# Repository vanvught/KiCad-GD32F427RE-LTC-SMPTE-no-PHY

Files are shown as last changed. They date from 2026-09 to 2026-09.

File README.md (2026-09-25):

# KiCad GD32F427RE LTC-SMPTE no PHY

Firmware [https://github.com/vanvught/GD32F427RE-LTC-SMPTE](https://github.com/vanvught/GD32F427RE-LTC-SMPTE)

More information [https://www.gd32-dmx.org](https://www.gd32-dmx.org)

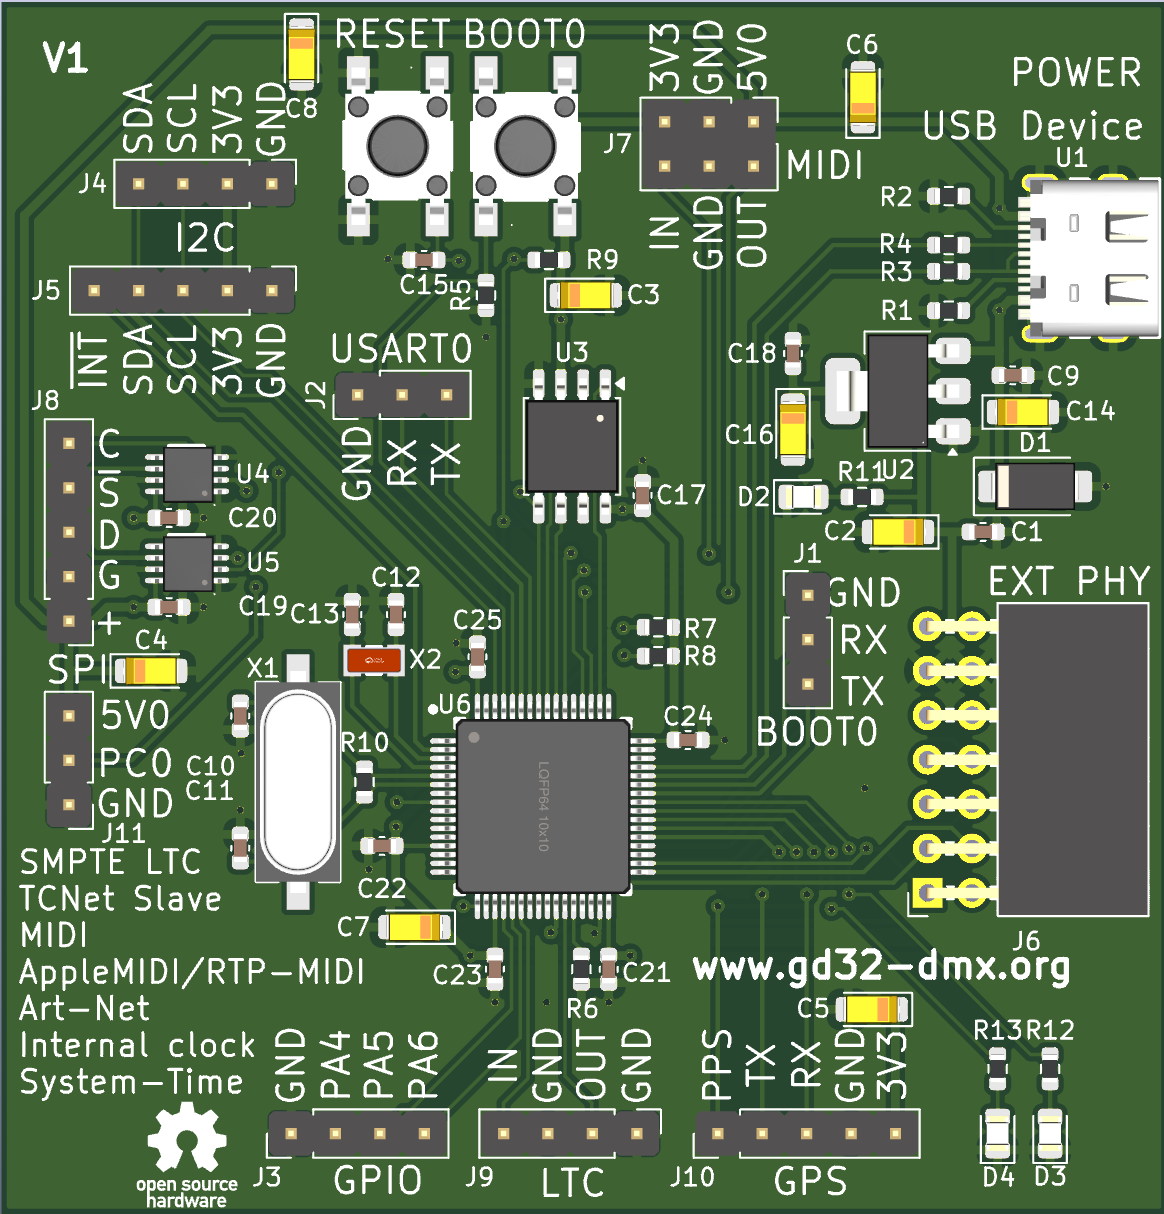
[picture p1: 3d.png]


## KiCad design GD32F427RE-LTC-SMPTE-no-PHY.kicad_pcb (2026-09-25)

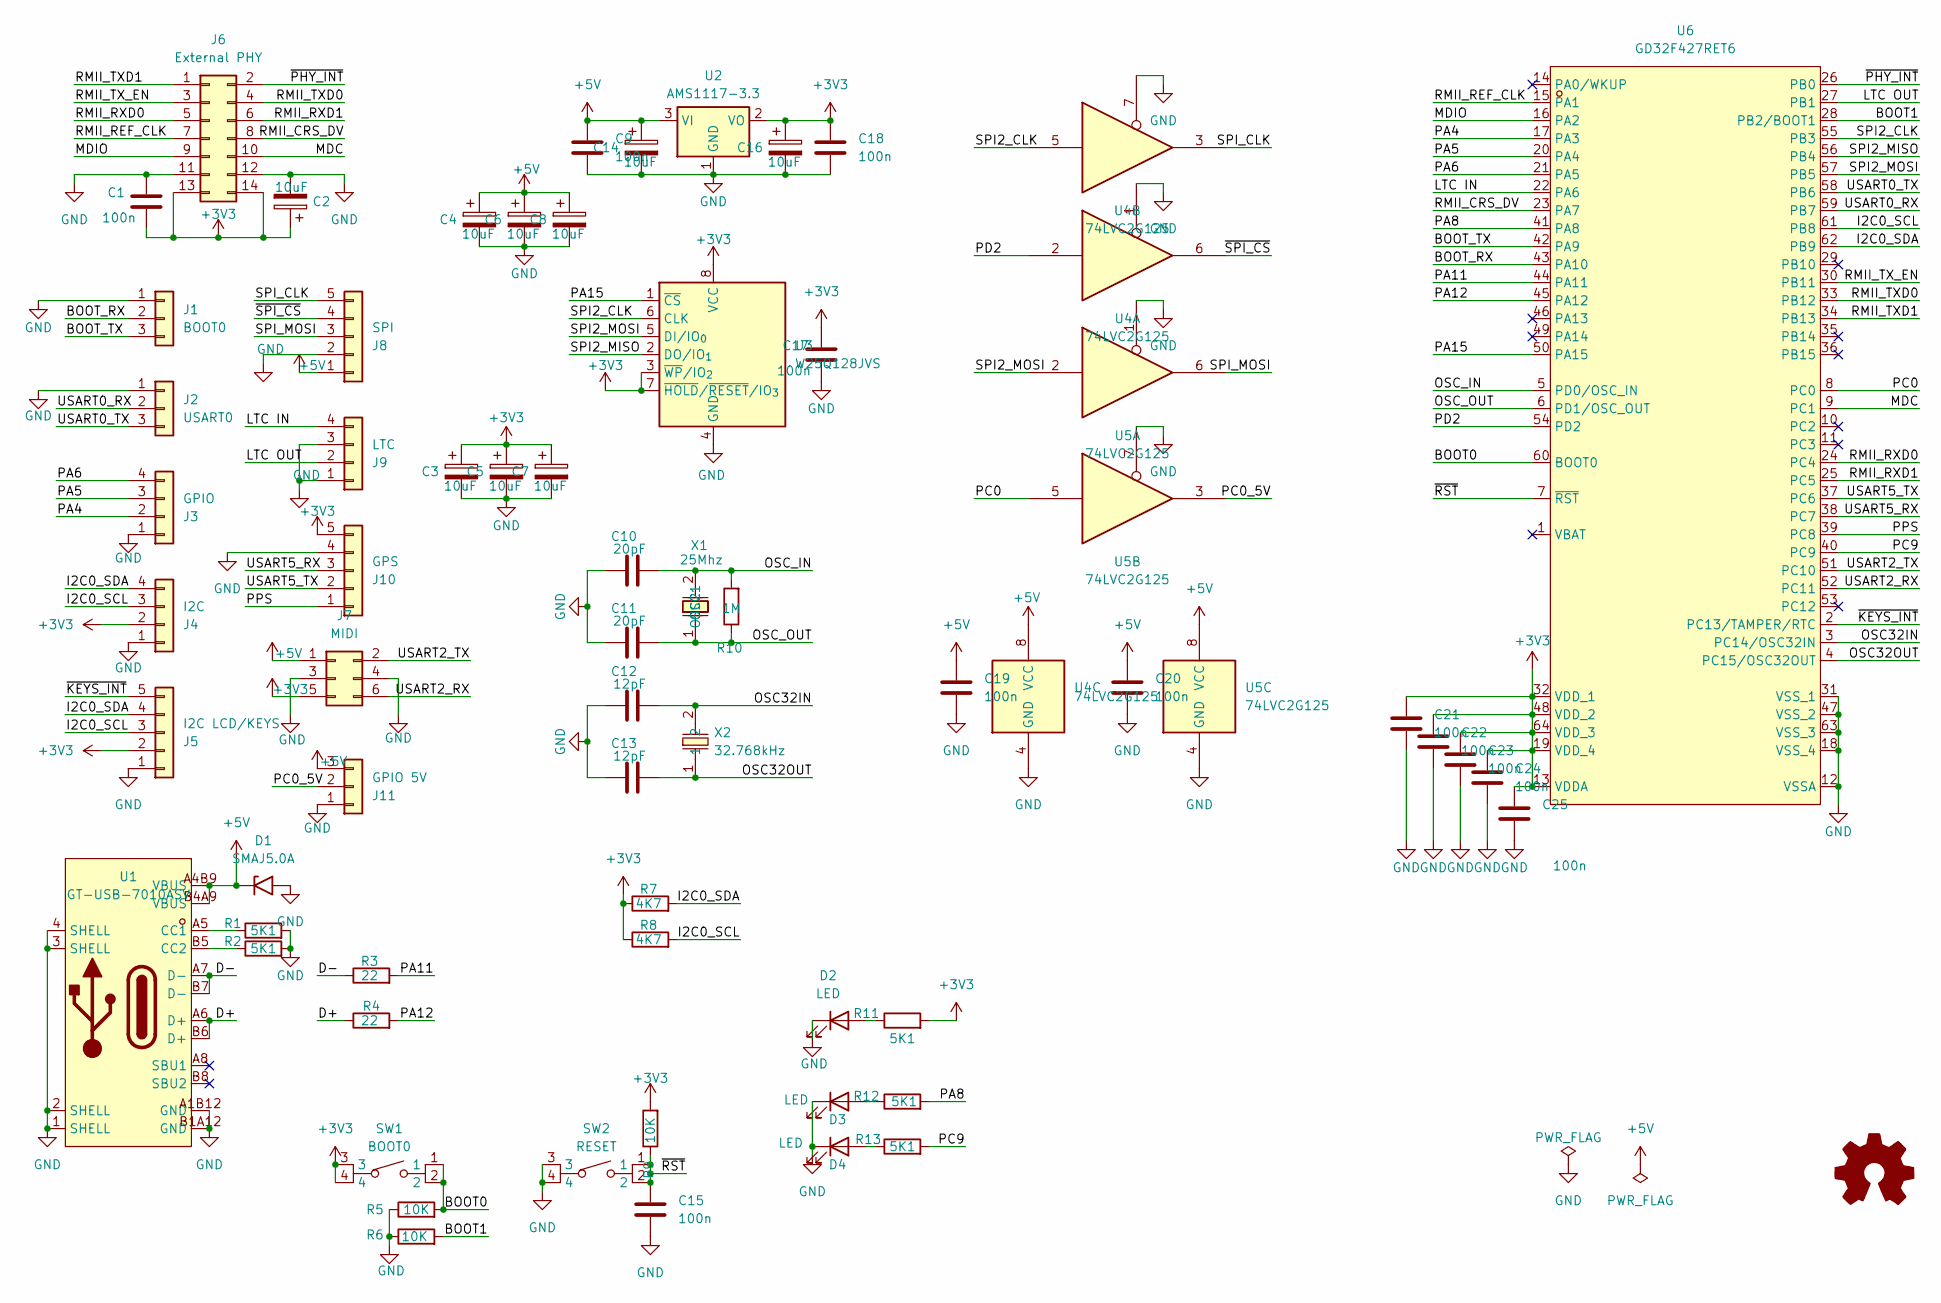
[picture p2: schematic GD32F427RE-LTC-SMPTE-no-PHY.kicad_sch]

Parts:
C1, C9, C15, C17, C18, C19, C20, C21, C22, C23, C24, C25: 100n; C_0603_1608Metric; LCSC Part C14663
C2, C3, C4, C5, C6, C7, C8, C14, C16: 10uF; CP_EIA-3216-18_Kemet-A; LCSC Part C7171
C10, C11: 20pF; C_0603_1608Metric; LCSC Part C1648
C12, C13: 12pF; C_0603_1608Metric; LCSC Part C38523
D1: SMAJ5.0A; D_SMA; LCSC Part C113952
D2, D3, D4: LED; LED_0805_2012Metric; LCSC Part C2297
J1: BOOT0; PinHeader_1x03_P2.54mm_Vertical
J2: USART0; PinHeader_1x03_P2.54mm_Vertical
J3: GPIO; PinHeader_1x04_P2.54mm_Vertical
J4: I2C; PinHeader_1x04_P2.54mm_Vertical
J5: I2C LCD/KEYS; PinHeader_1x05_P2.54mm_Vertical
J6: External PHY; PinSocket_2x07_P2.54mm_Horizontal
J7: MIDI; PinHeader_2x03_P2.54mm_Vertical
J8: SPI; PinHeader_1x05_P2.54mm_Vertical
J9: LTC; PinHeader_1x04_P2.54mm_Vertical
J10: GPS; PinHeader_1x05_P2.54mm_Vertical
J11: GPIO 5V; PinHeader_1x03_P2.54mm_Vertical
R1, R2, R11, R12, R13: 5K1; R_0603_1608Metric; LCSC Part C23186
R3, R4: 22; R_0603_1608Metric; LCSC Part C23345
R5, R6, R9: 10K; R_0603_1608Metric; LCSC Part C25804
R7, R8: 4K7; R_0603_1608Metric; LCSC Part C23162
R10: 1M; R_0603_1608Metric; LCSC Part C22935
SW1: BOOT0; KEY-SMD_4P-L6.0-W6.0-P4.50-LS9.0; MPN PTS645SM43SMTR92LFS; LCSC Part C221880
SW2: RESET; KEY-SMD_4P-L6.0-W6.0-P4.50-LS9.0; MPN PTS645SM43SMTR92LFS; LCSC Part C221880
SYM1: Logo_Open_Hardware_Small; OSHW-Logo_5.7x6mm_SilkScreen
U1: GT-USB-7010ASV; USB-C-SMD_G-SWITCH_GT-USB-7010ASV; MPN GT-USB-7010ASV; LCSC Part C2988369
U2: AMS1117-3.3; SOT-223-3_TabPin2
U3: W25Q128JVS; SOIC-8_5.3x5.3mm_P1.27mm; LCSC Part C97521
U4, U5: 74LVC2G125; SM8_L3.2-W2.9-P0.65-LS4.3-BR; LCSC Part C206035
U6: GD32F427RET6; LQFP-64_L10.0-W10.0-P0.50-LS12.0-BL; MPN GD32F407RET6; LCSC Part C2688748
X1: 25Mhz; HC-49S_L11.4-W4.8; MPN X49SM25MSD2SC; LCSC Part C14872
X2: 32.768kHz; FC-135R_L3.2-W1.5; MPN Q13FC13500004; LCSC Part C32346

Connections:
+3V3: C1.2, C2.1, C3.1, C5.1, C7.1, C16.1, C17.1, C18.1, C21.1, C22.1, C23.1, C24.1, C25.1, J4.2, J5.2, J6.13, J6.14, J7.5, J10.5, R7.1, R8.1, R9.2, R11.2, SW1.3, SW1.4, U2.2 (VO), U3.3 (~WP/IO_{2}), U3.7 (~HOLD/~RESET/IO_{3}), U3.8 (VCC), U6.13 (VDDA), U6.19 (VDD_4), U6.32 (VDD_1), U6.48 (VDD_2), U6.64 (VDD_3)
+5V: C4.1, C6.1, C8.1, C9.1, C14.1, C19.1, C20.1, D1.1 (A1), J7.1, J8.1, J11.3, U1.A4B9 (VBUS), U1.B4A9 (VBUS), U2.3 (VI), U4.8 (VCC), U5.8 (VCC)
/BOOT0: R5.2, SW1.1, SW1.2, U6.60 (BOOT0)
/BOOT1: R6.2, U6.28 (PB2/BOOT1)
/BOOT_RX: J1.2, U6.43 (PA10)
/BOOT_TX: J1.3, U6.42 (PA9)
/D+: R4.1, U1.A6 (D+), U1.B6 (D+)
/D-: R3.1, U1.A7 (D-), U1.B7 (D-)
/I2C0_SCL: J4.3, J5.3, R8.2, U6.61 (PB8)
/I2C0_SDA: J4.4, J5.4, R7.2, U6.62 (PB9)
/LTC IN: J9.4, U6.22 (PA6)
/LTC OUT: J9.2, U6.27 (PB1)
/MDC: J6.10, U6.9 (PC1)
/MDIO: J6.9, U6.16 (PA2)
/OSC32IN: C12.2, U6.3 (PC14/OSC32IN), X2.2
/OSC32OUT: C13.2, U6.4 (PC15/OSC32OUT), X2.1
/OSC_IN: C10.2, R10.2, U6.5 (PD0/OSC_IN), X1.2 (OSC2)
/OSC_OUT: C11.2, R10.1, U6.6 (PD1/OSC_OUT), X1.1 (OSC1)
/PA4: J3.2, U6.17 (PA3)
/PA5: J3.3, U6.20 (PA4)
/PA6: J3.4, U6.21 (PA5)
/PA8: R12.2, U6.41 (PA8)
/PA11: R3.2, U6.44 (PA11)
/PA12: R4.2, U6.45 (PA12)
/PA15: U3.1 (~CS), U6.50 (PA15)
/PC0: U5.5, U6.8 (PC0)
/PC0_5V: J11.2, U5.3
/PC9: R13.2, U6.40 (PC9)
/PD2: U4.2, U6.54 (PD2)
/PPS: J10.1, U6.39 (PC8)
/RMII_CRS_DV: J6.8, U6.23 (PA7)
/RMII_REF_CLK: J6.7, U6.15 (PA1)
/RMII_RXD0: J6.5, U6.24 (PC4)
/RMII_RXD1: J6.6, U6.25 (PC5)
/RMII_TXD0: J6.4, U6.33 (PB12)
/RMII_TXD1: J6.1, U6.34 (PB13)
/RMII_TX_EN: J6.3, U6.30 (PB11)
/SPI2_CLK: U3.6 (CLK), U4.5, U6.55 (PB3)
/SPI2_MISO: U3.2 (DO/IO_{1}), U6.56 (PB4)
/SPI2_MOSI: U3.5 (DI/IO_{0}), U5.2, U6.57 (PB5)
/SPI_CLK: J8.5, U4.3
/SPI_MOSI: J8.3, U5.6
/USART0_RX: J2.2, U6.59 (PB7)
/USART0_TX: J2.3, U6.58 (PB6)
/USART2_RX: J7.6, U6.52 (PC11)
/USART2_TX: J7.2, U6.51 (PC10)
/USART5_RX: J10.3, U6.38 (PC7)
/USART5_TX: J10.2, U6.37 (PC6)
/~KEYS_INT: J5.5, U6.2 (PC13/TAMPER/RTC)
/~PHY_INT: J6.2, U6.26 (PB0)
/~RST: C15.1, R9.1, SW2.1, SW2.2, U6.7 (~RST)
/~SPI_CS: J8.4, U4.6
GND: C1.1, C2.2, C3.2, C4.2, C5.2, C6.2, C7.2, C8.2, C9.2, C10.1, C11.1, C12.1, C13.1, C14.2, C15.2, C16.2, C17.2, C18.2, C19.2, C20.2, C21.2, C22.2, C23.2, C24.2, C25.2, D1.2 (A2), D2.1 (K), D3.1 (K), D4.1 (K), J1.1, J2.1, J3.1, J4.1, J5.1, J6.11, J6.12, J7.3, J7.4, J8.2, J9.1, J9.3, J10.4, J11.1, R1.2, R2.2, R5.1, R6.1, SW2.3, SW2.4, U1.1 (SHELL), U1.2 (SHELL), U1.3 (SHELL), U1.4 (SHELL), U1.A1B12 (GND), U1.B1A12 (GND), U2.1 (GND), U3.4 (GND), U4.1, U4.4 (GND), U4.7, U5.1, U5.4 (GND), U5.7, U6.12 (VSSA), U6.18 (VSS_4), U6.31 (VSS_1), U6.47 (VSS_2), U6.63 (VSS_3)
unnamed: D2.2 (A), R11.1
unnamed: D3.2 (A), R12.1
unnamed: D4.2 (A), R13.1
unnamed: R1.1, U1.A5 (CC1)
unnamed: R2.1, U1.B5 (CC2)

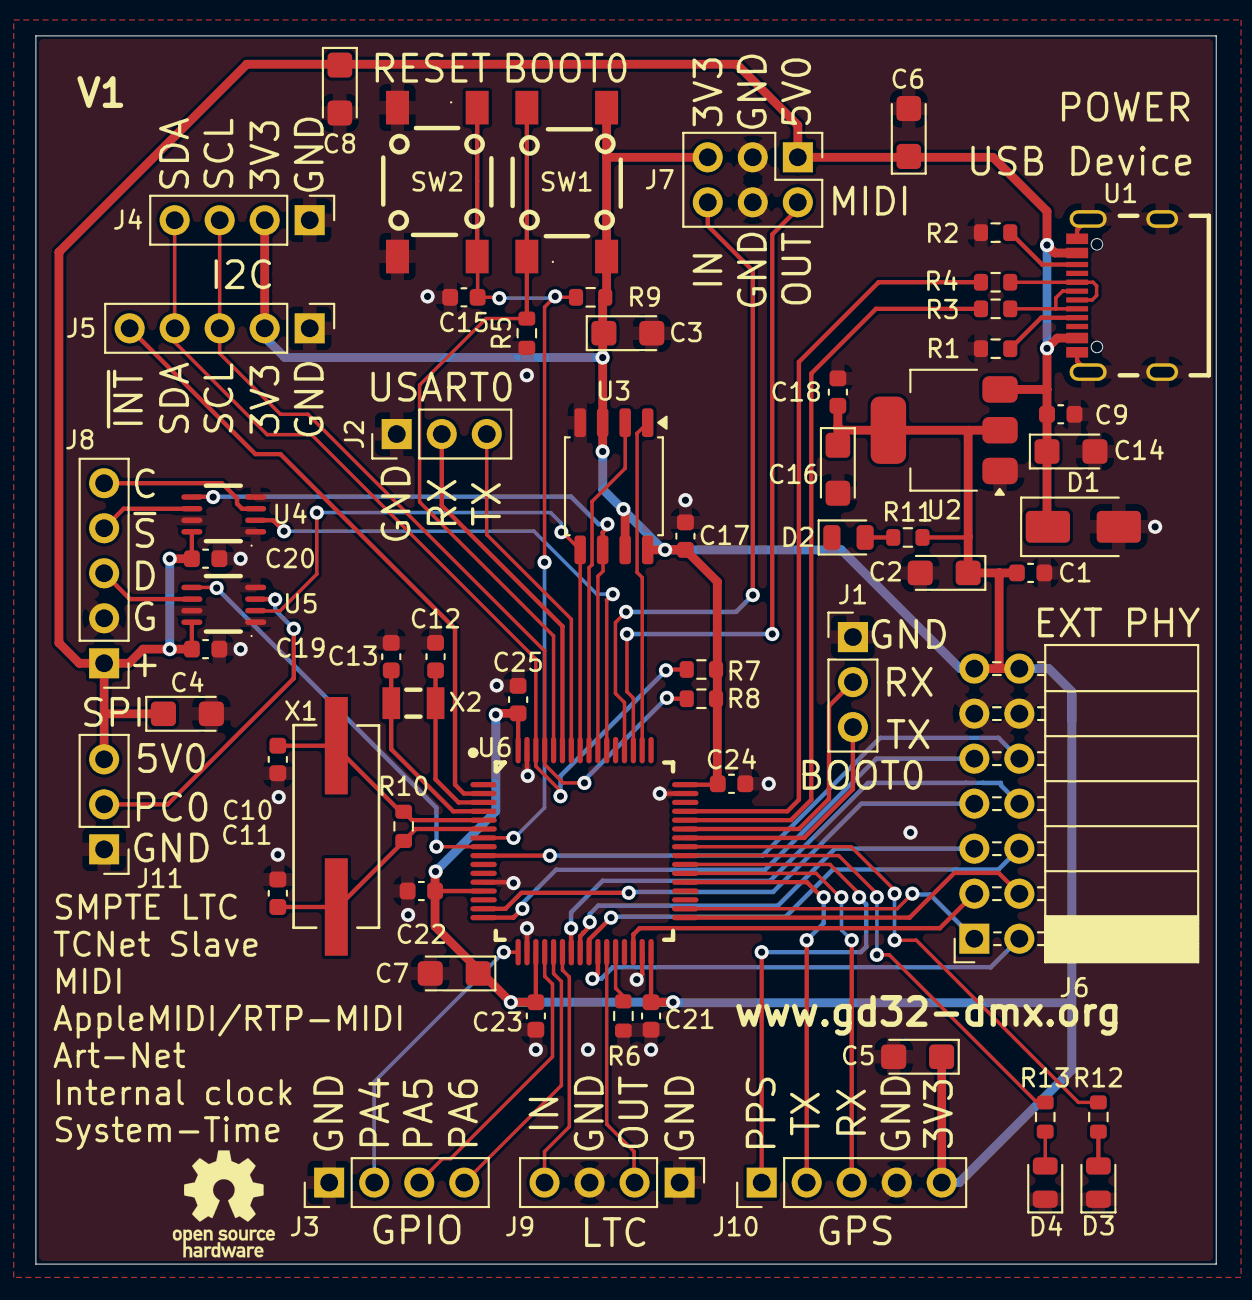
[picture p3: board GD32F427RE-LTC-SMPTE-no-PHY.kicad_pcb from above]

Board: 2 copper layers, 66.6 x 69.3 mm, 64 parts (0 on the bottom side), 58 nets.

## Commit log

2026-09-25 Add KiCad project and production files
    Initialize the GD32F427RE LTC-SMPTE no PHY KiCad project and add generated manufacturing outputs, including the BOM, component placement CSV, and a 3D board render for assembly and review.
    [GD32F427RE-LTC-SMPTE-no-PHY.kicad_pcb, GD32F427RE-LTC-SMPTE-no-PHY.kicad_sch]
2026-09-30 Fix PA3-PA5 pin labels
    Correct the PA3, PA4, and PA5 labels in the schematic and PCB silkscreen so the header pin names match the intended mapping. The 3D board render is updated to reflect the corrected labeling.
2026-09-30 Regenerate production export artifacts
    Refreshes the production outputs by updating the generated ZIP package and IPC netlist export. The netlist now lists the PA8 and PC9 via records in a different position (same coordinates/connections)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
2026-10-24 Fix PA3-PA5 net mapping and shift J6 connector
    Corrects the net assignments on the MCU pins (PA3, PA4, PA5) and the corresponding J6 header pads, which were off by one (PA4/PA5/PA6). Tracks and vias are renamed to match.
    Moves J6 (2x07 socket) 0.9 mm in X (102 -> 102.9) and reroutes the +3V3, MDC, RMII_CRS_DV, RMII_RXD1, RMII_TXD0, RMII_TXD1 and PHY_INT traces to follow it. Adds three GND stitching vias and refreshes the GND zone fills.
2026-10-24 Add front-copper filled polygons
    Add two filled F.Cu polygons to the PCB layout.
